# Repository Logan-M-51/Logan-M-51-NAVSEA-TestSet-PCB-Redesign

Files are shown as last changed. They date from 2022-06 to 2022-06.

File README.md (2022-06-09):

# Logan-M-51-NAVSEA-TestSet-PCB-Redesign
This project was completed as a senior design project as one of the graduation requirements for the Computer Engineering and Systems
program at the university of Washington Tacoma. 
This particular project was sponsored by NAVSEA, and completed with a group of three students.

This assignment was given to UWT students to extend the lifespan of the detonator test set circuitry shelf life. 
The current solution is over half a century old and is experiencing more failures as time goes on.
Thus, this redesign mimics the same functionality of the original test set while in a PCB format.
This allows NAVSEA engineers to replace the components in use withouth having to retrain test set operators.

Solution was tested in LTSpice, as well as on breadboard recreations.

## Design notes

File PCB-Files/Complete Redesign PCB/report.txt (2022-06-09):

Info: Reading netlist file 'C:\Users\Logan\OneDrive\Desktop\navsea\navsea.net'.

Info: Using reference designators to match symbols and footprints.

Info: Processing symbol 'R32:Resistor_THT:R_Axial_DIN0411_L9.9mm_D3.6mm_P25.40mm_Horizontal'.
Info: Processing symbol 'Q7:Package_TO_SOT_THT:TO-5-3'.
Info: Processing symbol 'R21:Resistor_THT:R_Axial_DIN0309_L9.0mm_D3.2mm_P25.40mm_Horizontal'.
Info: Processing symbol 'R16:Resistor_THT:R_Axial_DIN0204_L3.6mm_D1.6mm_P1.90mm_Vertical'.
Info: Processing symbol 'R20:Resistor_THT:R_Axial_DIN0309_L9.0mm_D3.2mm_P25.40mm_Horizontal'.
Info: Processing symbol 'R28:Resistor_THT:R_Axial_DIN0204_L3.6mm_D1.6mm_P1.90mm_Vertical'.
Info: Processing symbol 'R19:Resistor_THT:R_Axial_DIN0309_L9.0mm_D3.2mm_P25.40mm_Horizontal'.
Info: Processing symbol 'R15:Resistor_THT:R_Axial_DIN0204_L3.6mm_D1.6mm_P1.90mm_Vertical'.
Info: Processing symbol 'R12:Resistor_THT:R_Axial_DIN0309_L9.0mm_D3.2mm_P25.40mm_Horizontal'.
Info: Processing symbol 'Q2:Package_TO_SOT_THT:TO-5-3'.
Info: Processing symbol 'R11:Resistor_THT:R_Axial_DIN0309_L9.0mm_D3.2mm_P25.40mm_Horizontal'.
Info: Processing symbol 'R13:Resistor_THT:R_Axial_DIN0204_L3.6mm_D1.6mm_P1.90mm_Vertical'.
Info: Processing symbol 'R5:Resistor_THT:R_Axial_DIN0309_L9.0mm_D3.2mm_P25.40mm_Horizontal'.
Info: Processing symbol 'R29:Resistor_THT:R_Axial_DIN0204_L3.6mm_D1.6mm_P1.90mm_Vertical'.
Info: Processing symbol 'R3:Resistor_THT:R_Axial_DIN0309_L9.0mm_D3.2mm_P25.40mm_Horizontal'.
Info: Processing symbol 'R10:Resistor_THT:R_Axial_DIN0204_L3.6mm_D1.6mm_P1.90mm_Vertical'.
Info: Processing symbol 'R2:Resistor_THT:R_Axial_DIN0309_L9.0mm_D3.2mm_P25.40mm_Horizontal'.
Info: Processing symbol 'Q8:Package_TO_SOT_THT:TO-5-3'.
Info: Processing symbol 'R14:Resistor_THT:R_Axial_DIN0309_L9.0mm_D3.2mm_P15.24mm_Horizontal'.
Info: Processing symbol 'R9:Resistor_THT:R_Axial_DIN0204_L3.6mm_D1.6mm_P1.90mm_Vertical'.
Info: Processing symbol 'R8:Resistor_THT:R_Axial_DIN0309_L9.0mm_D3.2mm_P15.24mm_Horizontal'.
Info: Processing symbol 'R30:Resistor_THT:R_Axial_DIN0204_L3.6mm_D1.6mm_P1.90mm_Vertical'.
Info: Processing symbol 'R27:Resistor_THT:R_Axial_DIN0204_L3.6mm_D1.6mm_P1.90mm_Vertical'.
Info: Processing symbol 'R6:Resistor_THT:R_Axial_DIN0204_L3.6mm_D1.6mm_P1.90mm_Vertical'.
Info: Processing symbol 'R26:Resistor_THT:R_Axial_DIN0204_L3.6mm_D1.6mm_P1.90mm_Vertical'.
Info: Processing symbol 'Q10:Package_TO_SOT_THT:TO-5-3'.
Info: Processing symbol 'R24:Resistor_THT:R_Axial_DIN0204_L3.6mm_D1.6mm_P1.90mm_Vertical'.
Info: Processing symbol 'R4:Resistor_THT:R_Axial_DIN0204_L3.6mm_D1.6mm_P1.90mm_Vertical'.
Info: Processing symbol 'R23:Resistor_THT:R_Axial_DIN0204_L3.6mm_D1.6mm_P1.90mm_Vertical'.
Info: Processing symbol 'R31:Resistor_THT:R_Axial_DIN0204_L3.6mm_D1.6mm_P1.90mm_Vertical'.
Info: Processing symbol 'R22:Resistor_THT:R_Axial_DIN0204_L3.6mm_D1.6mm_P1.90mm_Vertical'.
Info: Processing symbol 'R1:Resistor_THT:R_Axial_DIN0204_L3.6mm_D1.6mm_P1.90mm_Vertical'.
Info: Processing symbol 'R18:Resistor_THT:R_Axial_DIN0204_L3.6mm_D1.6mm_P1.90mm_Vertical'.
Info: Processing symbol 'Q9:Package_TO_SOT_THT:TO-5-3'.
Info: Processing symbol 'R25:Resistor_THT:R_Axial_DIN0204_L3.6mm_D1.6mm_P1.90mm_Vertical'.
Info: Processing symbol 'R7:Resistor_THT:R_Axial_DIN0204_L3.6mm_D1.6mm_P1.90mm_Vertical'.
Info: Processing symbol 'R17:Resistor_THT:R_Axial_DIN0204_L3.6mm_D1.6mm_P1.90mm_Vertical'.
Info: Processing symbol 'Q12:Package_TO_SOT_THT:TO-5-3'.
Info: Processing symbol 'Q13:Package_TO_SOT_THT:TO-5-3'.
Info: Processing symbol 'Q11:Package_TO_SOT_THT:TO-5-3'.
Info: Processing symbol 'Q1:Package_TO_SOT_THT:TO-5-3'.
Info: Processing symbol 'Q3:Package_TO_SOT_THT:TO-5-3'.
Info: Processing symbol 'Q4:Package_TO_SOT_THT:TO-5-3'.
Info: Processing symbol 'Q5:Package_TO_SOT_THT:TO-5-3'.
Info: Processing symbol 'Q6:Package_TO_SOT_THT:TO-5-3'.
Info: Processing symbol 'D11:Diode_THT:D_5KPW_P7.62mm_Vertical_AnodeUp'.
Info: Processing symbol 'D9:Diode_THT:D_5KPW_P7.62mm_Vertical_AnodeUp'.
Info: Processing symbol 'D8:Diode_THT:D_5KPW_P7.62mm_Vertical_AnodeUp'.
Info: Processing symbol 'D7:Diode_THT:D_5KPW_P7.62mm_Vertical_AnodeUp'.
Info: Processing symbol 'D6:Diode_THT:D_5KPW_P7.62mm_Vertical_AnodeUp'.
Info: Processing symbol 'D5:Diode_THT:D_5KPW_P7.62mm_Vertical_AnodeUp'.
Info: Processing symbol 'D4:Diode_THT:D_5KPW_P7.62mm_Vertical_AnodeUp'.
Info: Processing symbol 'D3:Diode_THT:D_5KPW_P7.62mm_Vertical_AnodeUp'.
Info: Processing symbol 'D2:Diode_THT:D_5KPW_P7.62mm_Vertical_AnodeUp'.
Info: Processing symbol 'D10:Diode_THT:D_5KPW_P7.62mm_Vertical_AnodeUp'.
Info: Processing symbol 'D1:Diode_THT:D_5KPW_P7.62mm_Vertical_AnodeUp'.
Info: Processing symbol 'D25:Diode_THT:D_5KPW_P7.62mm_Vertical_AnodeUp'.
Info: Processing symbol 'D15:Diode_THT:D_5KPW_P7.62mm_Vertical_AnodeUp'.
Info: Processing symbol 'D14:Diode_THT:D_5KPW_P7.62mm_Vertical_AnodeUp'.
Info: Processing symbol 'D13:Diode_THT:D_5KPW_P7.62mm_Vertical_AnodeUp'.
Info: Processing symbol 'D12:Diode_THT:D_5KPW_P7.62mm_Vertical_AnodeUp'.
Info: Processing symbol 'VR1:Diode_THT:D_5KPW_P7.62mm_Vertical_AnodeUp'.
Info: Processing symbol 'VR2:Diode_THT:D_5KPW_P7.62mm_Vertical_AnodeUp'.
Info: Processing symbol 'C1:Capacitor_THT:CP_Radial_D4.0mm_P1.50mm'.
Info: Processing symbol 'C7:Capacitor_THT:CP_Radial_D4.0mm_P1.50mm'.
Info: Processing symbol 'C5:Capacitor_THT:CP_Radial_D4.0mm_P1.50mm'.
Info: Processing symbol 'C4:Capacitor_THT:CP_Radial_D4.0mm_P1.50mm'.
Info: Processing symbol 'C3:Capacitor_THT:CP_Radial_D4.0mm_P1.50mm'.
Info: Processing symbol 'C2:Capacitor_THT:CP_Radial_D4.0mm_P1.50mm'.
Info: Processing symbol 'C9:Capacitor_THT:CP_Axial_L10.0mm_D4.5mm_P15.00mm_Horizontal'.
Info: Processing symbol 'C8:Capacitor_THT:CP_Axial_L10.0mm_D4.5mm_P15.00mm_Horizontal'.
Info: Processing symbol 'C6:Capacitor_THT:CP_Axial_L10.0mm_D4.5mm_P15.00mm_Horizontal'.
Info: Processing symbol 'J1:TE_2-826576-0_1x20_P3.96mm_Vertical'.
Add Q2 (footprint 'Package_TO_SOT_THT:TO-5-3').
Add R32 (footprint 'Resistor_THT:R_Axial_DIN0411_L9.9mm_D3.6mm_P25.40mm_Horizontal').
Add Q12 (footprint 'Package_TO_SOT_THT:TO-5-3').
Add R21 (footprint 'Resistor_THT:R_Axial_DIN0309_L9.0mm_D3.2mm_P25.40mm_Horizontal').
Add Q13 (footprint 'Package_TO_SOT_THT:TO-5-3').
Add R20 (footprint 'Resistor_THT:R_Axial_DIN0309_L9.0mm_D3.2mm_P25.40mm_Horizontal').
Add Q11 (footprint 'Package_TO_SOT_THT:TO-5-3').
Add R19 (footprint 'Resistor_THT:R_Axial_DIN0309_L9.0mm_D3.2mm_P25.40mm_Horizontal').
Add Q1 (footprint 'Package_TO_SOT_THT:TO-5-3').
Add R12 (footprint 'Resistor_THT:R_Axial_DIN0309_L9.0mm_D3.2mm_P25.40mm_Horizontal').
Add Q3 (footprint 'Package_TO_SOT_THT:TO-5-3').
Add R11 (footprint 'Resistor_THT:R_Axial_DIN0309_L9.0mm_D3.2mm_P25.40mm_Horizontal').
Add Q4 (footprint 'Package_TO_SOT_THT:TO-5-3').
Add R5 (footprint 'Resistor_THT:R_Axial_DIN0309_L9.0mm_D3.2mm_P25.40mm_Horizontal').
Add Q5 (footprint 'Package_TO_SOT_THT:TO-5-3').
Add R3 (footprint 'Resistor_THT:R_Axial_DIN0309_L9.0mm_D3.2mm_P25.40mm_Horizontal').
Add Q6 (footprint 'Package_TO_SOT_THT:TO-5-3').
Add R2 (footprint 'Resistor_THT:R_Axial_DIN0309_L9.0mm_D3.2mm_P25.40mm_Horizontal').
Add D11 (footprint 'Diode_THT:D_5KPW_P7.62mm_Vertical_AnodeUp').
Add R14 (footprint 'Resistor_THT:R_Axial_DIN0309_L9.0mm_D3.2mm_P15.24mm_Horizontal').
Add D9 (footprint 'Diode_THT:D_5KPW_P7.62mm_Vertical_AnodeUp').
Add R8 (footprint 'Resistor_THT:R_Axial_DIN0309_L9.0mm_D3.2mm_P15.24mm_Horizontal').
Add D8 (footprint 'Diode_THT:D_5KPW_P7.62mm_Vertical_AnodeUp').
Add R27 (footprint 'Resistor_THT:R_Axial_DIN0204_L3.6mm_D1.6mm_P1.90mm_Vertical').
Add D7 (footprint 'Diode_THT:D_5KPW_P7.62mm_Vertical_AnodeUp').
Add R26 (footprint 'Resistor_THT:R_Axial_DIN0204_L3.6mm_D1.6mm_P1.90mm_Vertical').
Add D6 (footprint 'Diode_THT:D_5KPW_P7.62mm_Vertical_AnodeUp').
Add R24 (footprint 'Resistor_THT:R_Axial_DIN0204_L3.6mm_D1.6mm_P1.90mm_Vertical').
Add D5 (footprint 'Diode_THT:D_5KPW_P7.62mm_Vertical_AnodeUp').
Add R23 (footprint 'Resistor_THT:R_Axial_DIN0204_L3.6mm_D1.6mm_P1.90mm_Vertical').
Add D4 (footprint 'Diode_THT:D_5KPW_P7.62mm_Vertical_AnodeUp').
Add R22 (footprint 'Resistor_THT:R_Axial_DIN0204_L3.6mm_D1.6mm_P1.90mm_Vertical').
Add D3 (footprint 'Diode_THT:D_5KPW_P7.62mm_Vertical_AnodeUp').
Add R18 (footprint 'Resistor_THT:R_Axial_DIN0204_L3.6mm_D1.6mm_P1.90mm_Vertical').
Add D2 (footprint 'Diode_THT:D_5KPW_P7.62mm_Vertical_AnodeUp').
Add R25 (footprint 'Resistor_THT:R_Axial_DIN0204_L3.6mm_D1.6mm_P1.90mm_Vertical').
Add D10 (footprint 'Diode_THT:D_5KPW_P7.62mm_Vertical_AnodeUp').
Add R17 (footprint 'Resistor_THT:R_Axial_DIN0204_L3.6mm_D1.6mm_P1.90mm_Vertical').
Add D1 (footprint 'Diode_THT:D_5KPW_P7.62mm_Vertical_AnodeUp').
Add R16 (footprint 'Resistor_THT:R_Axial_DIN0204_L3.6mm_D1.6mm_P1.90mm_Vertical').
Add D25 (footprint 'Diode_THT:D_5KPW_P7.62mm_Vertical_AnodeUp').
Add R15 (footprint 'Resistor_THT:R_Axial_DIN0204_L3.6mm_D1.6mm_P1.90mm_Vertical').
Add D15 (footprint 'Diode_THT:D_5KPW_P7.62mm_Vertical_AnodeUp').
Add R13 (footprint 'Resistor_THT:R_Axial_DIN0204_L3.6mm_D1.6mm_P1.90mm_Vertical').
Add D14 (footprint 'Diode_THT:D_5KPW_P7.62mm_Vertical_AnodeUp').
Add R10 (footprint 'Resistor_THT:R_Axial_DIN0204_L3.6mm_D1.6mm_P1.90mm_Vertical').
Add D13 (footprint 'Diode_THT:D_5KPW_P7.62mm_Vertical_AnodeUp').
Add R9 (footprint 'Resistor_THT:R_Axial_DIN0204_L3.6mm_D1.6mm_P1.90mm_Vertical').
Add D12 (footprint 'Diode_THT:D_5KPW_P7.62mm_Vertical_AnodeUp').
Add R6 (footprint 'Resistor_THT:R_Axial_DIN0204_L3.6mm_D1.6mm_P1.90mm_Vertical').
Add VR1 (footprint 'Diode_THT:D_5KPW_P7.62mm_Vertical_AnodeUp').
Add R4 (footprint 'Resistor_THT:R_Axial_DIN0204_L3.6mm_D1.6mm_P1.90mm_Vertical').
Add VR2 (footprint 'Diode_THT:D_5KPW_P7.62mm_Vertical_AnodeUp').
Add R1 (footprint 'Resistor_THT:R_Axial_DIN0204_L3.6mm_D1.6mm_P1.90mm_Vertical').
Add C1 (footprint 'Capacitor_THT:CP_Radial_D4.0mm_P1.50mm').
Add R7 (footprint 'Resistor_THT:R_Axial_DIN0204_L3.6mm_D1.6mm_P1.90mm_Vertical').
Add C7 (footprint 'Capacitor_THT:CP_Radial_D4.0mm_P1.50mm').
Add R28 (footprint 'Resistor_THT:R_Axial_DIN0204_L3.6mm_D1.6mm_P1.90mm_Vertical').
Add C5 (footprint 'Capacitor_THT:CP_Radial_D4.0mm_P1.50mm').
Add R29 (footprint 'Resistor_THT:R_Axial_DIN0204_L3.6mm_D1.6mm_P1.90mm_Vertical').
Add C4 (footprint 'Capacitor_THT:CP_Radial_D4.0mm_P1.50mm').
Add R30 (footprint 'Resistor_THT:R_Axial_DIN0204_L3.6mm_D1.6mm_P1.90mm_Vertical').
Add C3 (footprint 'Capacitor_THT:CP_Radial_D4.0mm_P1.50mm').
Add R31 (footprint 'Resistor_THT:R_Axial_DIN0204_L3.6mm_D1.6mm_P1.90mm_Vertical').
Add C2 (footprint 'Capacitor_THT:CP_Radial_D4.0mm_P1.50mm').
Add Q7 (footprint 'Package_TO_SOT_THT:TO-5-3').
Add C9 (footprint 'Capacitor_THT:CP_Axial_L10.0mm_D4.5mm_P15.00mm_Horizontal').
Add Q8 (footprint 'Package_TO_SOT_THT:TO-5-3').
Add C8 (footprint 'Capacitor_THT:CP_Axial_L10.0mm_D4.5mm_P15.00mm_Horizontal').
Add Q9 (footprint 'Package_TO_SOT_THT:TO-5-3').
Add C6 (footprint 'Capacitor_THT:CP_Axial_L10.0mm_D4.5mm_P15.00mm_Horizontal').
Add Q10 (footprint 'Package_TO_SOT_THT:TO-5-3').
Add J1 (footprint 'TE_2-826576-0_1x20_P3.96mm_Vertical').

Info: Total warnings: 0, errors: 0.

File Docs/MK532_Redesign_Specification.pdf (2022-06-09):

# NAVSEA Design Specification

Zachary Pratt (ZP), Logan Miller (LM), Jairo De La Mora (JM)

Version 0.9 from 5/24/2022

## Revision History

Revision | Date | Author(s) | Description
0.1 | 10/28/2021 | ZP, LM, JM | Created
0.2 | 10/31/2021 | ZP, LM, JM | Added to requirements, enumerated sections
0.3 | 11/14/2021 | ZP, LM, JM | Updated after Nov. 5th sponsor meeting
0.4 | 11/28/2021 | ZP, LM, JM | Added Ethical Considerations,
0.5 | 1/24/2022 | ZP, LM, JM | Added notes to system design and bill of materials
0.6 | 2/21/2022 | ZP, LM, JM | Added to bill of materials, system architecture, and require-
| | | ments
0.7 | 4/10/2022 | ZP, LM, JM | Added to bill of materials
0.8 | 5/15/2022 | ZP, LM, JM | Updated system architecture, system design
0.9 | 5/24/2022 | ZP, LM, JM | updated system architecture picture, BOM, system design

## Contents

## 1 Overview

This project entails the recreation of the MK.532, this device has the purpose of testing detonator resistances within the Navy’s systems. The preexisting device is considered antiquated, recreating the device is being done to prevent future issues with its use.

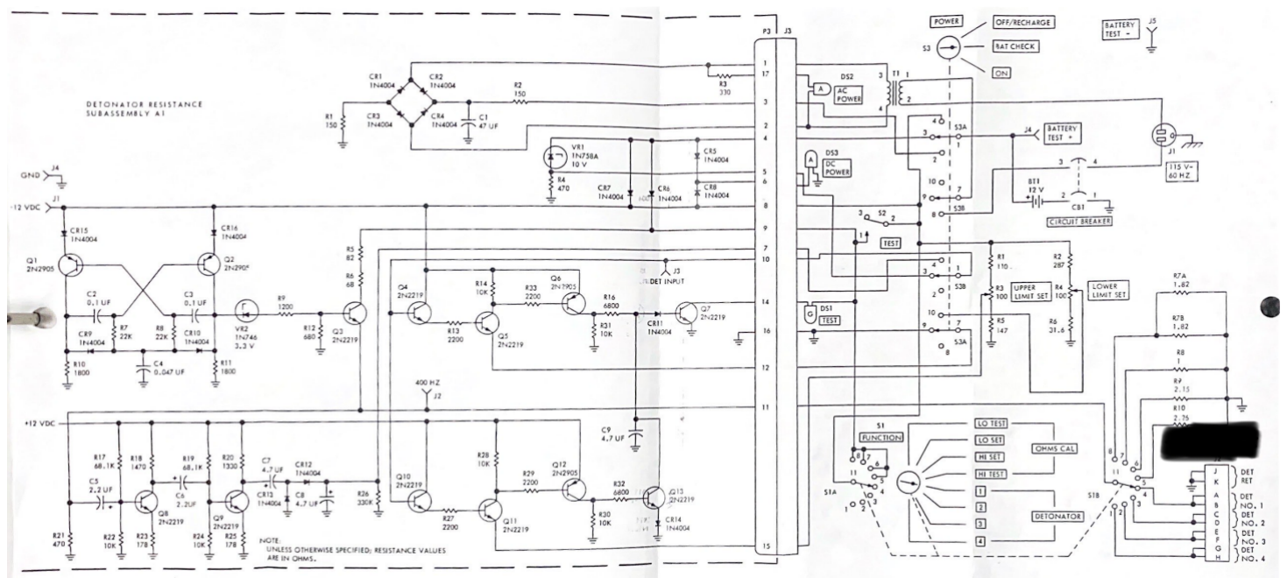
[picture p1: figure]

Figure 1: Original Schematic

## 2 Requirements

Must accurately detect resistances between 1.0 and 2.5 ohms. Values found outside of this range will be signaled via a light on the test set enclosure. The functionality of the redesigned test set must perfectly replicate the original including the wired connections between the test set and the detonator resistors. This will be done to ensure continuity for NAVSEA operators of the test set. Operator tests must also match the previously expected results.

## 3 System Architecture

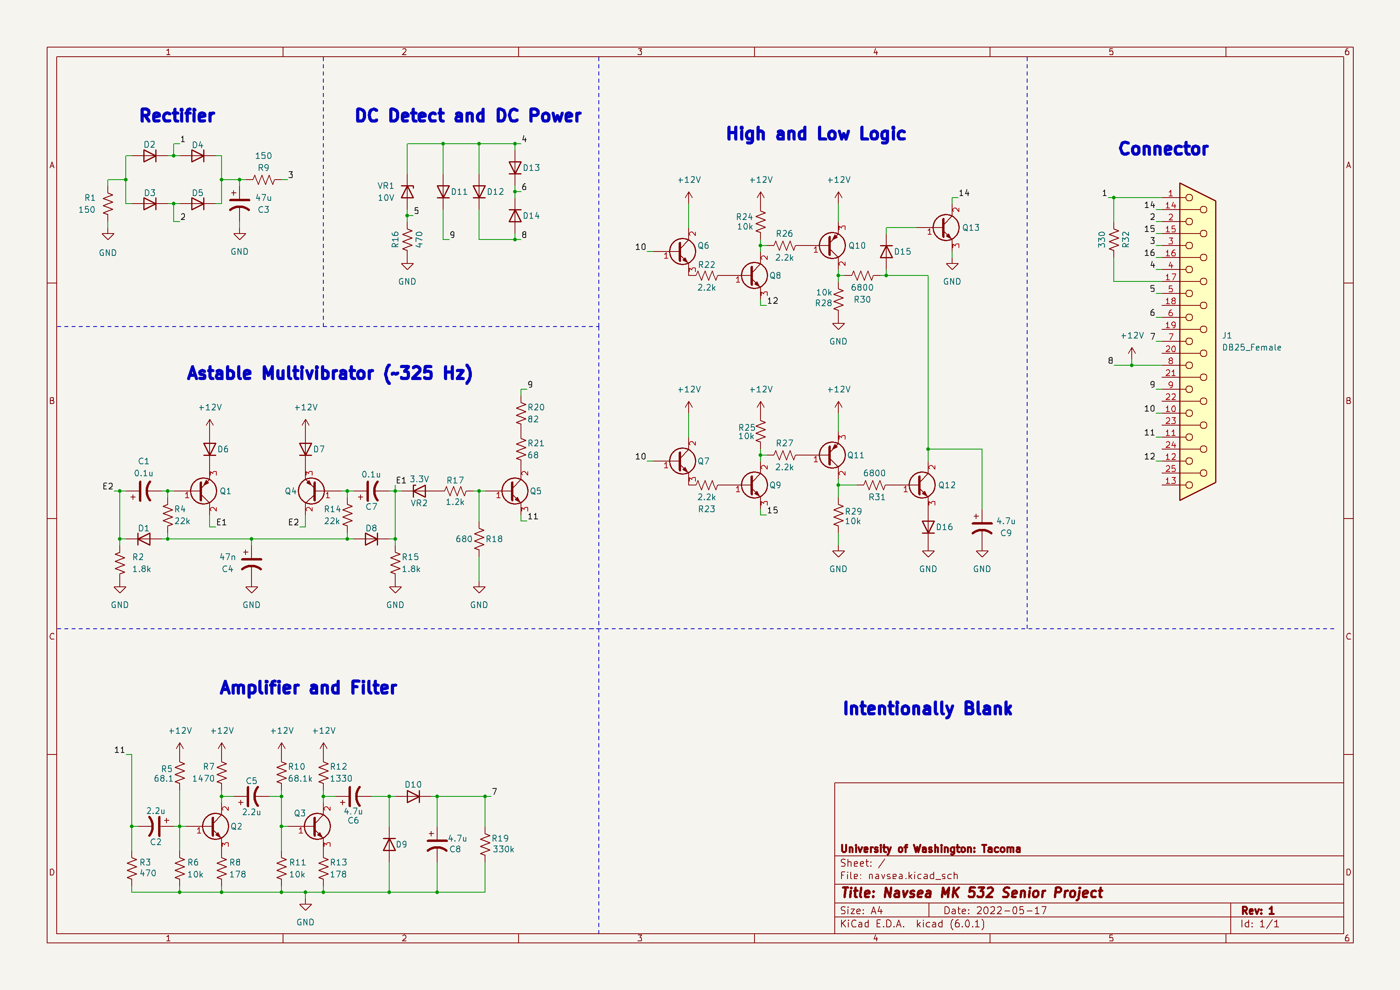
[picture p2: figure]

Figure 2: System Architecture

### 3.1 Original Architecture

The architecture of the final deliverable printed circuit board (PCB) will entirely be decided on the predecessor test kit. This includes all of the internal segments of this attached design. The PCB replicates the circuit logic from the original schematics. This can be seen in Figure 2 which shows the circuitry of the PCB mimicking the logic side of the original schematic (Figure 1). The circuit produces a 325 hz square wave signal out of the Astable Multivibrator, this signal goes across the DET resistor and the 470 ohm resistor (from the amplifier circuit) in parallel. The voltage drop of this signal is then sent through the Amplifier and Filter section which makes the difference in resistance more easily measured in DC voltage. This is then sent to the High and Low Logic which compares voltage values to verify if the resistor is within range or not.

The user interface side is meant to connect to the PCB through the female connector. If a smaller form factor is deemed necessary for the test set, it would be possible to expand upon the final deliverable to include this circuitry as well.

### 3.2 Proposed Alternative

The proposed alternative would replace the square wave generator, amplifier circuit, as well as the logic gate sections. The same logic can be done with a Wheatstone bridge and an accompanying op amp for the purpose of a comparator. The Wheatstone’s variable resistor (R2) will replace the Upper and Lower limit sets of the original design. This new potentiometer will encompass the acceptable range of ohms (1.0
- 2.25), with an output LED attached across Vg. This design allows the operator to directly test the value of the DET resistor (Rx). When resistance values in the Wheatstone bridge are balanced Vg will have no voltage across it, thus extinguishing the output LED. Therefore if the operator is able to extinguish the light when rotating the potentiometer (R2) from one extreme to another, then the resistor is within range. This is a promising alternative as it would reduce costs as it contains less components than the existing logic. This route was ultimately not taken as it would change the required test procedures for test set operators. Additionally, this was tested and functional in digital simulations, but it was not determined if physical creations of this circuit will

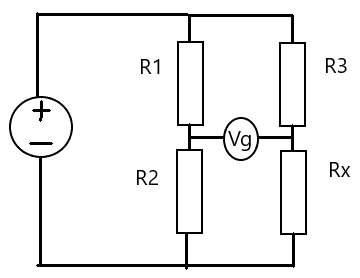
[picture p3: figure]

Figure 3: Wheatstone Bridge

## 4 System Design

Our design process will mostly pertain to the use of digital software such as KiCAD. This design will mimic the previously made design of the test set as we are expected to maintain it’s uses with the new design.

### 4.1 User Interface

The ”user interface” of this schematic involved all of the circuitry to the right of the large divider going down the middle of the NAVSEA provided schematic. These switches are what will interact with the redesigned PCB. The current housing of the MK.532 splits the user interface and logic into two sections. The user interface section is entirely comprised of wires and rotary switches. without the time to alter the housing, the PCB redesign has not included the user interface sections as it is less challenging to change and can be completed by those who follow up this project in implementing the PCB if a smaller form factor is deemed necessary.

### 4.2 AC to DC Converter

This section is a simple rectifier ciruit that converts the alternating current into direct current in order to charge the battery that operates the test equitment.

### 4.3 Square Wave Generator

This circuit produces a square wave with an amplitude of approximately eighty millivolts. This is the signal used to measure the resistance of the resistors. The test resistor is in parallel with another resistor at the beginning of the Amplifier circuit, this is done so that the small difference in resistance is more measure-able with the later amplified DC voltage.

### 4.4 Amplifier Circuit

This piece is what takes in the square wave signal and amplifies the value and converts it to a DC voltage. This is done so that the logic gates further along the circuit can compare this value to a dialed in voltage to compare the detonator resistors with test resistors. This makes it possible to identify the range of the detonator resistor.

### 4.5 Logic Gate Section

This circuit is what compares and voltage values to determine whether the DET resistance is in range or not. This is displayed via a incandescent bulb in the original design, or an LED from the new redesign named TEST.

## 5 Bill of Materials

The previous designs bill of materials was provided by Eric Theer, we have begun going over this list to validate their usability for our project. Due to change in sponsor expected deliverables this is no longer a primary concern as we are not expected to build a chip. Many of these items were not available for or use for various reasons. Because of this we will need to update the list accordingly. We will be using several parts not within military specifications. Thus final deliverables will require two sets of material lists. These will entail the components used for physical tests, and another to act as a list of potential components for NAVSEA to use in their implementation.

BOM

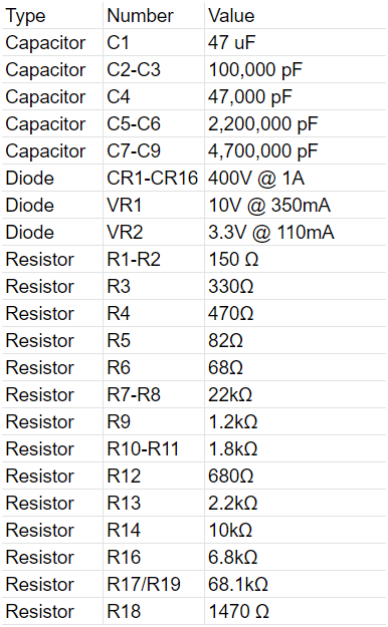
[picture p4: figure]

## 6 Ethical Considerations

This work will piggyback largely off the work of a previous senior design project student group led by Eric Theer, proper references to their original work will need to be maintained when completing this redesign.

In addition, the NAVSEA sponsors have declared that we will need to consider where our replacement parts are made. Specifically we were told components made in China were not to be permitted. All components used must meet Mil Spec requirements.

This test set is for the safety system of Naval systems. Thus our group is responsible for making sure that this test set is a reliable and long lasting method of ensuring the safety of military members.

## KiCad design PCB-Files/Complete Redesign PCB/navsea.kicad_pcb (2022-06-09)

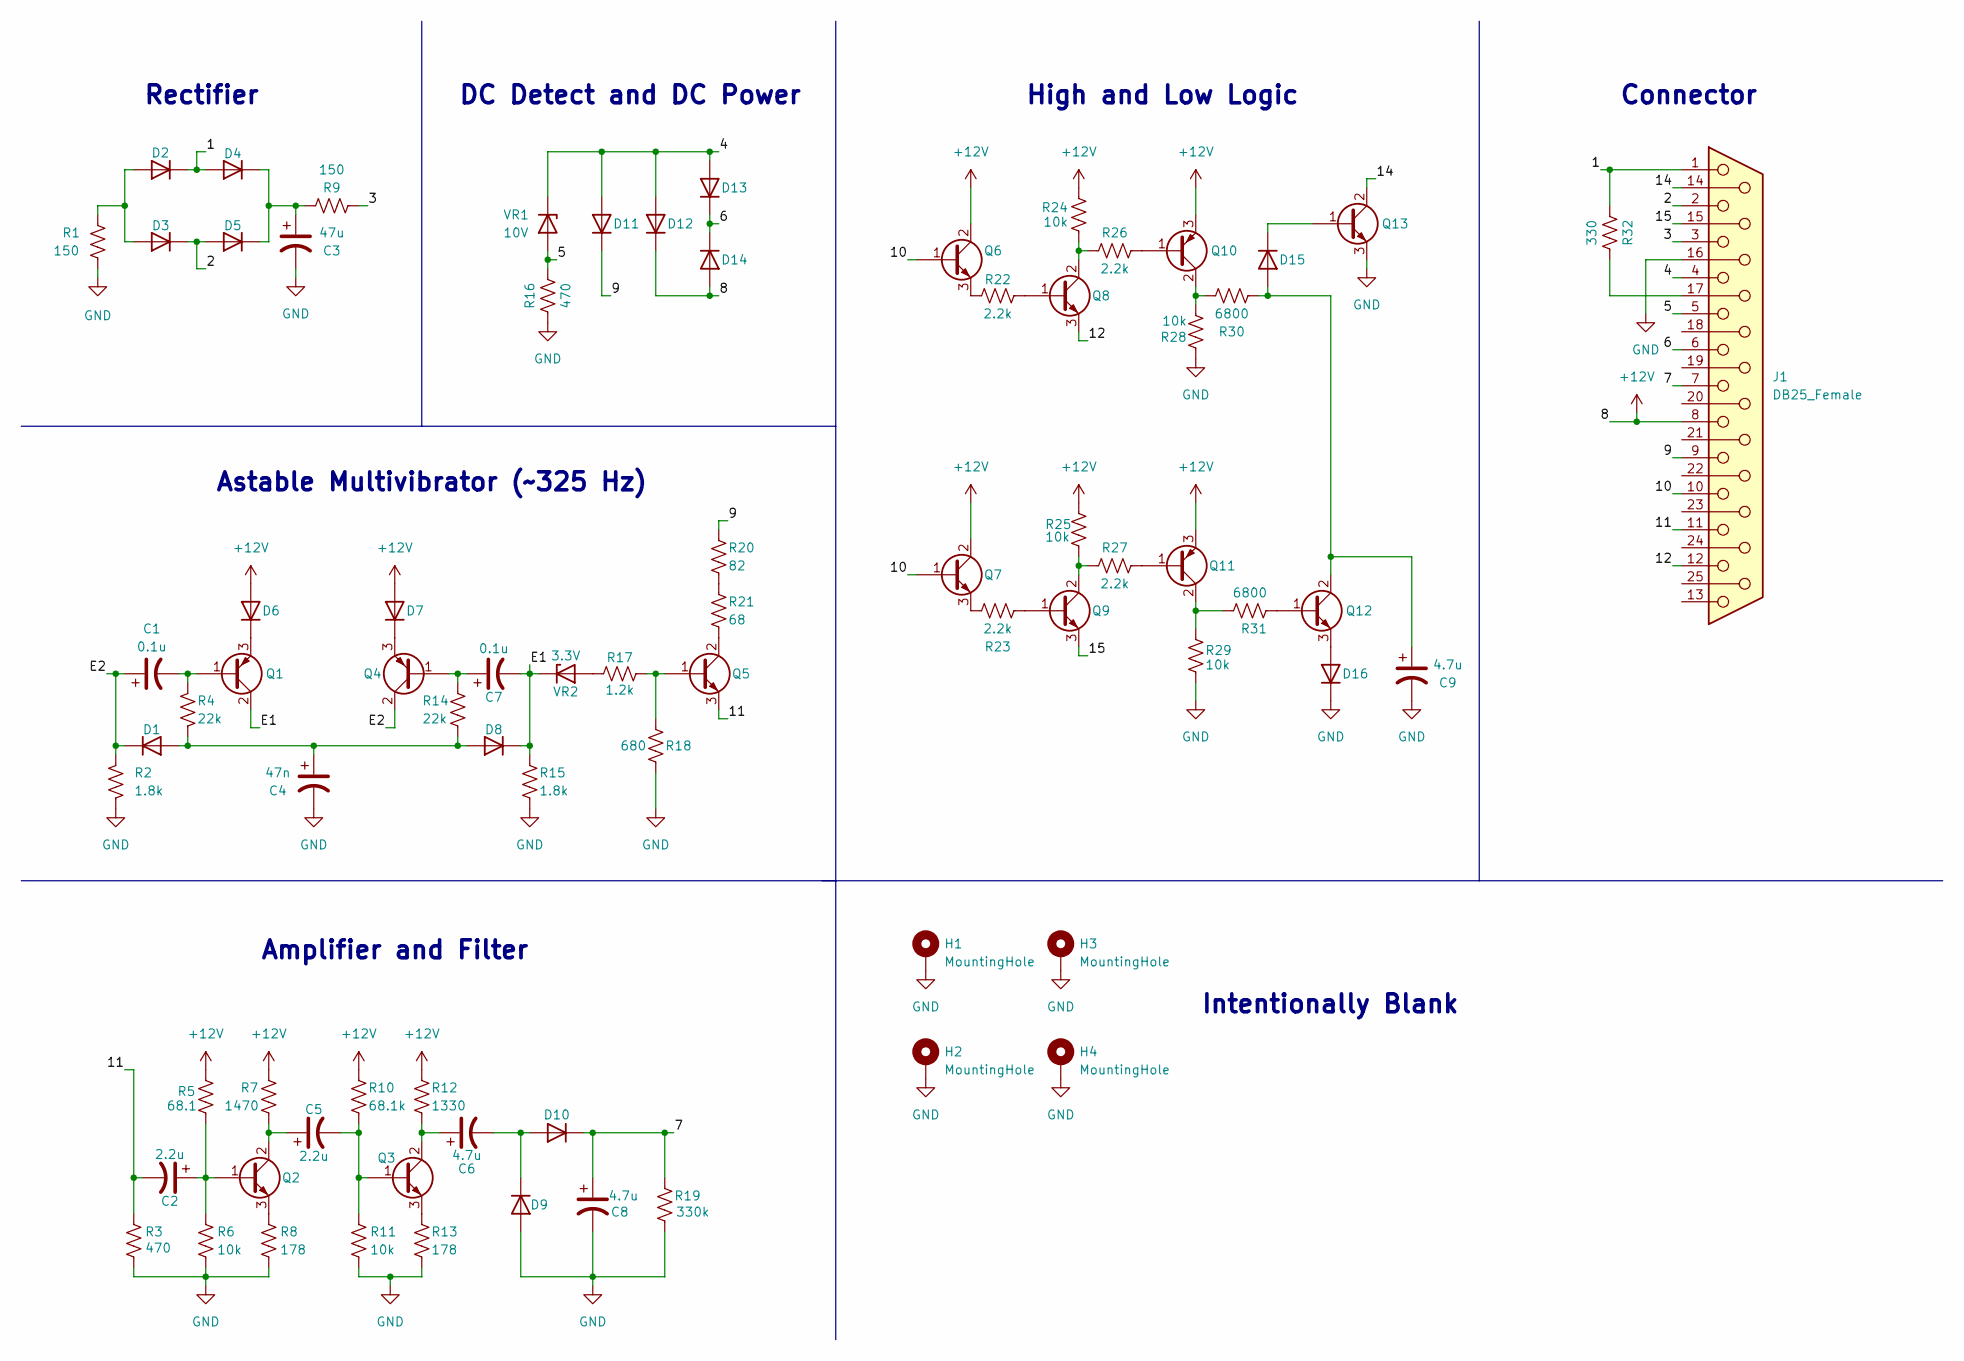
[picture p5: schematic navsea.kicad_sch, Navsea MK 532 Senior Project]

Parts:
C1, C7: 0.1u; CP_Radial_Tantal_D4.5mm_P2.50mm
C2, C5: 2.2u; CP_Radial_Tantal_D4.5mm_P2.50mm
C3: 47u; CP_Radial_D8.0mm_P3.50mm
C4: 47n; C_Axial_L5.1mm_D3.1mm_P10.00mm_Horizontal
C6: 4.7u; CP_Radial_D8.0mm_P3.50mm
C8, C9: 4.7u; CP_Axial_L10.0mm_D4.5mm_P15.00mm_Horizontal
D1, D2, D3, D4, D5, D6, D7, D8, D9, D10, D11, D12, D13, D14, D15, D16: D; D_DO-41_SOD81_P7.62mm_Horizontal
H1, H2, H3, H4: MountingHole; MountingHole_4.3mm_M4_Pad_Via
J1: DB25_Female; DSUB-25_Female_Horizontal_P2.77x2.84mm_EdgePinOffset4.94mm_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
Q1, Q4, Q10, Q11: PNP; TO-18-3
Q2, Q3, Q5, Q6, Q7, Q8, Q9, Q12, Q13: Q_NPN_BCE; TO-18-3
R1, R9: 150; R_Axial_DIN0414_L11.9mm_D4.5mm_P15.24mm_Horizontal
R2, R15: 1.8k; R_Axial_DIN0207_L6.3mm_D2.5mm_P7.62mm_Horizontal
R3, R16: 470; R_Axial_DIN0207_L6.3mm_D2.5mm_P7.62mm_Horizontal
R4, R14: 22k; R_Axial_DIN0207_L6.3mm_D2.5mm_P7.62mm_Horizontal
R5: 68.1; R_Axial_DIN0207_L6.3mm_D2.5mm_P7.62mm_Horizontal
R6, R11, R24, R25, R28, R29: 10k; R_Axial_DIN0207_L6.3mm_D2.5mm_P7.62mm_Horizontal
R7: 1470; R_Axial_DIN0207_L6.3mm_D2.5mm_P7.62mm_Horizontal
R8, R13: 178; R_Axial_DIN0207_L6.3mm_D2.5mm_P7.62mm_Horizontal
R10: 68.1k; R_Axial_DIN0207_L6.3mm_D2.5mm_P7.62mm_Horizontal
R12: 1330; R_Axial_DIN0207_L6.3mm_D2.5mm_P7.62mm_Horizontal
R17: 1.2k; R_Axial_DIN0207_L6.3mm_D2.5mm_P7.62mm_Horizontal
R18: 680; R_Axial_DIN0207_L6.3mm_D2.5mm_P7.62mm_Horizontal
R19: 330k; R_Axial_DIN0207_L6.3mm_D2.5mm_P7.62mm_Horizontal
R20: 82; R_Axial_DIN0207_L6.3mm_D2.5mm_P7.62mm_Horizontal
R21: 68; R_Axial_DIN0207_L6.3mm_D2.5mm_P7.62mm_Horizontal
R22, R23, R26, R27: 2.2k; R_Axial_DIN0207_L6.3mm_D2.5mm_P7.62mm_Horizontal
R30, R31: 6800; R_Axial_DIN0207_L6.3mm_D2.5mm_P7.62mm_Horizontal
R32: 330; R_Axial_DIN0207_L6.3mm_D2.5mm_P7.62mm_Horizontal
VR1: 10V; D_DO-41_SOD81_P7.62mm_Horizontal
VR2: 3.3V; D_DO-35_SOD27_P7.62mm_Horizontal

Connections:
+12V: D6.2 (A), D7.2 (A), D12.1 (K), D14.2 (A), J1.8, Q6.2 (C), Q7.2 (C), Q10.3 (E), Q11.3 (E), R5.1, R7.1, R10.1, R12.1, R24.1, R25.1
/1: D2.1 (K), D4.2 (A), J1.1, R32.2
/2: D3.1 (K), D5.2 (A), J1.2
/3: J1.3, R9.1
/4: D11.2 (A), D12.2 (A), D13.2 (A), J1.4, VR1.1 (K)
/5: J1.5, R16.2, VR1.2 (A)
/6: D13.1 (K), D14.1 (K), J1.6
/7: C8.1, D10.1 (K), J1.7, R19.1
/9: D11.1 (K), J1.9, R20.1
/10: J1.10, Q6.1 (B), Q7.1 (B)
/11: C2.2, J1.11, Q5.3 (E), R3.1
/12: J1.12, Q8.3 (E)
/14: J1.14, Q13.2 (C)
/15: J1.15, Q9.3 (E)
/E1: C7.2, D8.1 (K), Q1.2 (C), R15.1, VR2.1 (K)
/E2: C1.1, D1.1 (K), Q4.2 (C), R2.1
GND: C3.2, C4.2, C8.2, C9.2, D9.2 (A), D16.1 (K), H1.1, H2.1, H3.1, H4.1, J1.16, Q13.3 (E), R1.2, R2.2, R3.2, R6.2, R8.2, R11.2, R13.2, R15.2, R16.1, R18.1, R19.2, R28.2, R29.2
unnamed: C1.2, Q1.1 (B), R4.1
unnamed: C2.1, Q2.1 (B), R5.2, R6.1
unnamed: C3.1, D4.1 (K), D5.1 (K), R9.2
unnamed: C4.1, D1.2 (A), D8.2 (A), R4.2, R14.2
unnamed: C5.1, Q2.2 (C), R7.2
unnamed: C5.2, Q3.1 (B), R10.2, R11.1
unnamed: C6.1, Q3.2 (C), R12.2
unnamed: C6.2, D9.1 (K), D10.2 (A)
unnamed: C7.1, Q4.1 (B), R14.1
unnamed: C9.1, D15.2 (A), Q12.2 (C), R30.1
unnamed: D2.2 (A), D3.2 (A), R1.1
unnamed: D6.1 (K), Q1.3 (E)
unnamed: D7.1 (K), Q4.3 (E)
unnamed: D15.1 (K), Q13.1 (B)
unnamed: D16.2 (A), Q12.3 (E)
unnamed: J1.17, R32.1
unnamed: Q2.3 (E), R8.1
unnamed: Q3.3 (E), R13.1
unnamed: Q5.1 (B), R17.2, R18.2
unnamed: Q5.2 (C), R21.2
unnamed: Q6.3 (E), R22.1
unnamed: Q7.3 (E), R23.1
unnamed: Q8.1 (B), R22.2
unnamed: Q8.2 (C), R24.2, R26.1
unnamed: Q9.1 (B), R23.2
unnamed: Q9.2 (C), R25.2, R27.1
unnamed: Q10.1 (B), R26.2
unnamed: Q10.2 (C), R28.1, R30.2
unnamed: Q11.1 (B), R27.2
unnamed: Q11.2 (C), R29.1, R31.1
unnamed: Q12.1 (B), R31.2
unnamed: R17.1, VR2.2 (A)
unnamed: R20.2, R21.1

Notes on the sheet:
Rectifier
Connector
DC Detect and DC Power
Amplifier and Filter
Intentionally Blank
High and Low Logic
Astable Multivibrator (~325 Hz)

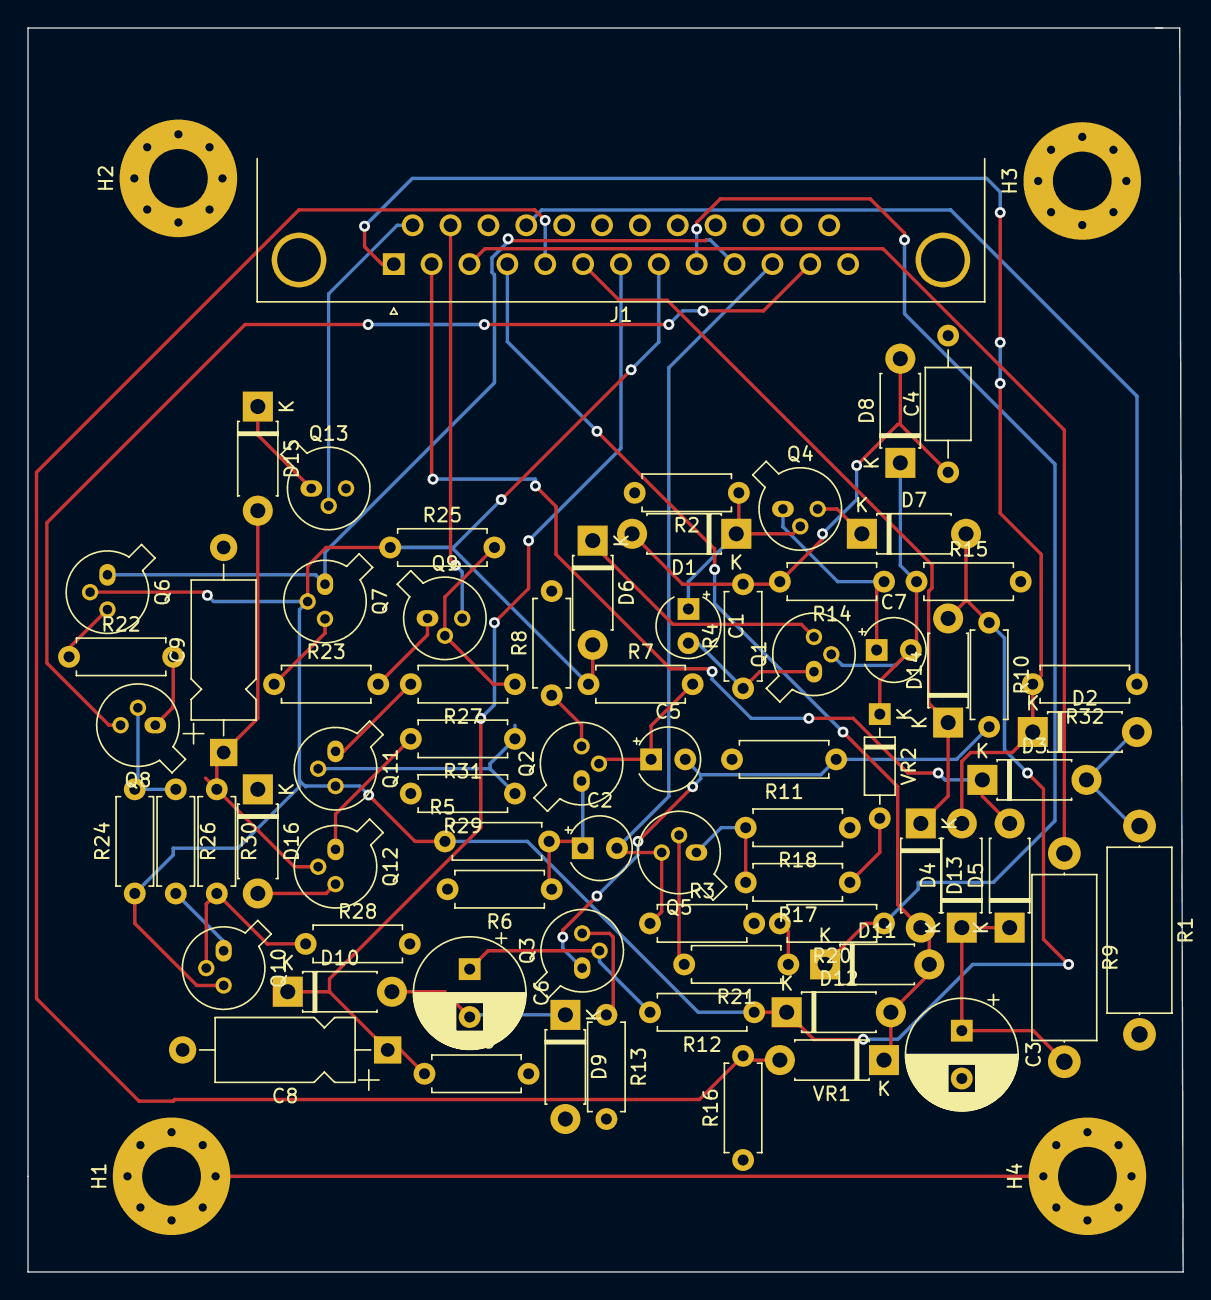
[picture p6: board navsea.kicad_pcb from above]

Board: 2 copper layers, 84.5 x 91.0 mm, 77 parts (0 on the bottom side), 50 nets.

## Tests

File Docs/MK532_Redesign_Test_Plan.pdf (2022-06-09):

# NAVSEA Test Plan

Zachary Pratt (ZP), Logan Miller (LM), Jairo De La Mora (JM)

Version 0.8 from 5/24/2022

Primary Point of Contact: daniel.lowney@navy.mil

## Revision History

Revision | Date | Author(s) | Description
0.1 | 10/24/2021 | ZP, LM, JM | Created
0.2 | 11/7/2021 | ZP, LM, JM | Added content to configurations to be tested, schedule, and
| | | system diagram to overview.
0.3 | 11/18/2021 | ZP, LM, JM | Added to Test Items, and Roles
0.4 | 1/17/2022 | ZP, LM, JM | Added to requirments and procedures
0.5 | 2/21/2022 | ZP, LM, JM | Added to procedures, schedule
0.6 | 4/10/2022 | ZP, LM, JM | Added to test configurations, procedures, deliverable,
| | | schedule
0.7 | 5/15/2022 | ZP, LM, JM | Updated Test Items, Configurations to be Tested, Roles,
| | | Schedule, Test Procedures
0.8 | 5/24/2022 | ZP, LM, JM | Testing Deliverables

## Contents

## 1 Overview

This project entails the recreation of the MK.532, this device has the purpose of testing detonator resistances within the Navy’s systems. The preexisting device is considered antiquated, recreating the device is being done to prevent future issues with its use.

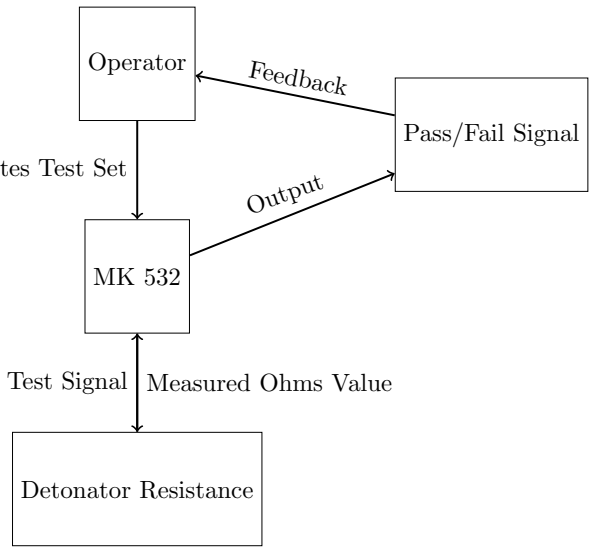
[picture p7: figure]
Operator; Detonator Resistance; Test Signal; Measured Ohms Value; Pass/Fail Signal; Output; Feedback

Technician Operates Test Set

Figure 1: System Diagram

## 2 Configurations to be Tested

### 2.1 Digital Simulations

The first test configuration is a digital recreation of the the circuit logic from the test circuit in modeling software LT Spice. This configuration is to be made so that the

### 2.2 Breadboard Recreation

New, modern parts with a fully integrated PCB unit as a replacement for the current internal electronics. The PCB will need to connect with the existing input dials and switches and produce the same outputs as the current MK 532.

### 2.3 Alternative Solutions

NAVSEA had reported some errors with their circuits in use. While it was assumed that these errors come from the obsolete components in use, NAVSEA asked we identify some possible alternatives for the MK.532 circuit logic. These alternative solutions are to be made using digital circuit modeling in LT Spice. These models will be validated through the same method as the digital recreations which is ensuring that it mimics the same behavior as the currently existing test equipment.

## 3 Test Items

The redesigned circuit must follow the expected behavior of the laid out test procedures made by NAVSEA documentation as summarized below

- Low Set/Test Calibration: CIRCUIT BREAKER and POWER in ON position, FUNCTION switch in the LO TEST position. Turn the UPPER LIMIT SET knob fully clockwise. Turn the LOWER LIMIT SET knob fully counter-clockwise. After doing this observe the TEST LED is on. Slowly turn the LOWER LIMIT SET knob clockwise until the test LED extinguishes. Then turn the LOWER LIMIT SET knob counter-clockwise to the value where TEST LED is lit. Place the FUNCTION switch in the DET 1 position, confirm the LED is still lit. This confirms the LED is within range. Repeat this process with the LO SET function position
- Hi Set/Test Calibration:CIRCUIT BREAKER and POWER in ON position, FUNCTION switch in the HI SET position. Turn the UPPER LIMIT SET knob fully clockwise. After doing this observe the TEST LED is on. Slowly turn the UPPER LIMIT SET knob counter-clockwise until the test LED extinguishes. Then turn the UPPER LIMIT SET knob clockwise to the value where TEST LED is lit. Place the FUNCTION switch in the DET 1 position, confirm the LED is still lit. This confirms the LED is within range. Repeat this process with the HI TEST function position
- PCB design would require separate testing as it is a completely new design that would need to function the same as the antiquated MK.532. The PCBs to be tested include three isolated models, each representing the independent circuitry of the three states. Then the complete redesign circuit as a whole. Actual printed PCB testing was not an expected deliverable from the sponsor due to time restraints, thus this is an optional item.

## 4 Testing Criteria

- The redesigned PCB must meet all requirements laid out by NAVSEA testing documentation on the previous iteration of the MK 532. This primarily includes LED read outs based on the state of the various switches as well as a spreadsheet of point to point values. This is to be done so that future operators of the test set can be used with no change in continuity for their training.

## 5 Test Procedures

NAVSEA has clarified our expected deliverable is a model of the redesign cards, we are not required to actually build the board if time does not allow it. From this the test procedures have changed to include only simulated tests. We will need to verify that all expected inputs work according to sponsor specifications.

### 5.1 Pass/Fail

The requirements of this card is to detect any resistances outside the range of 1.0 to 2.25 Ω displayed via the LED. Ensuring the redesign can correctly identify resistors as in or out of range (process described in 3 Test Items) is the main pass/fail requirment for this design.

### 5.2 Operator Tests

Along with the Low and High test/set calibrations, the redesign must follow the procedures of the user manual to maintain continuity for test equipment operators.

## 6 Testing Deliverables

The expected deliverables in regards to testing include digital recreations of the circuit that verify the design is functional. This along with a physical recreation on a bread board doing the same will suffice in verifying design. Engineers that follow up on this project will be required to do additional tests with the finished PCB.

## 7 Roles

- Relaying the allowed details/specifications of the project is the responsibility of Jairo and Logan.
- Final documentation for NAVSEA use will be the responsibility of Jairo and Logan.
- All members will be equally responsible for building the initial test circuits on breadboards and building the model.

## 8 Schedule

### 8.1 November

Research different methods of accurately measuring small resistances and needed knowledge of analog circuits.

### 8.2 December, January

Hands-on access to the MK 532 will be obtained after approvals from the Navy have been met. Testing of the original MK 532 will begin to determine which configuration to pursue.

### 8.3 February, March

As we have the schematic of the design we have begun recreating the circuit for testing on the breadboard as well as digital recreation for testing purposes. By the end of march we should have a physical test circuit for the design.

### 8.4 April

Ensure digital and physical recreations of the MK.532 recreate the appropriate behavior through testing. Identify possible alternative solutions for measuring resistance for the system through digital circuit modeling.

### 8.5 May, June

Finalize breadboard and digital recreations of the MK.532 circuit. Provide updates to documentation to include non-discussable information for NAVSEA use only.

## 9 Approvals

Ultimately the NAVSEA sponsors will need to verify the testing done with the final deliverables.
